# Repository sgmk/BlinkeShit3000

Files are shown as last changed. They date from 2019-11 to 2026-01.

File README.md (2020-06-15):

### BlinkeShit 3000

# New BlinkeShit for Bitwäscherei

An adapted and simplified version of the circuit of the 8Bit Mixtape / Gär-Lämpli to make a little BlinkeShit sign for our new hackerspace collective.

https://github.com/8BitMixtape/8Bit-Mixtape-NEO

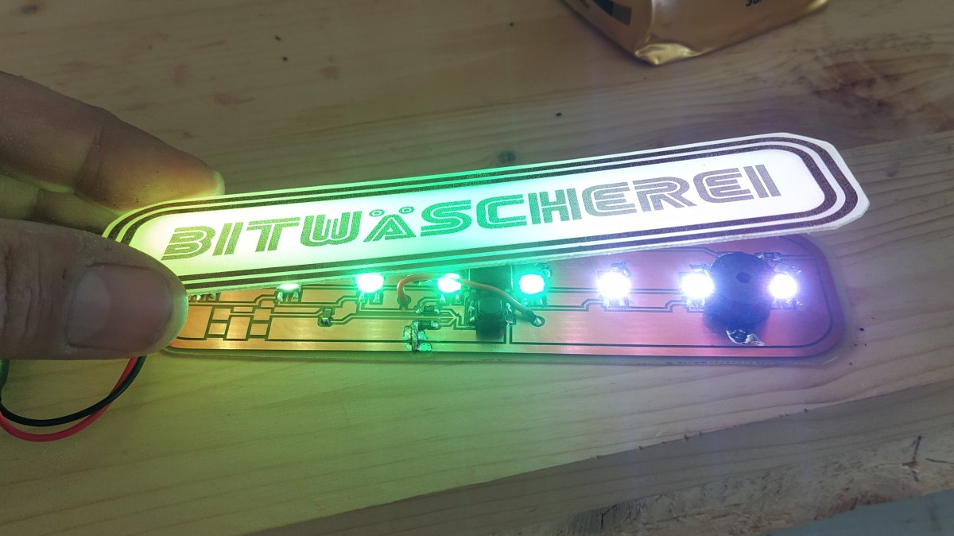
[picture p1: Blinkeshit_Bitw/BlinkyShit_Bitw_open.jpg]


You can design your custom front plate and etch it on PCB or use any other material, paper etc as diffusor.

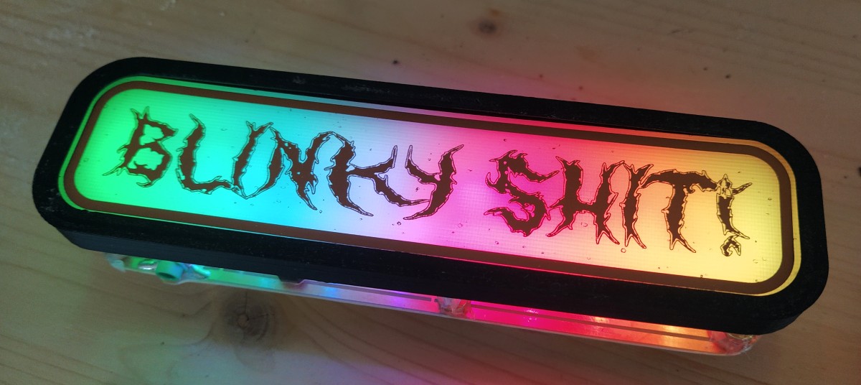
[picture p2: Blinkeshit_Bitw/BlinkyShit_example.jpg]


Upload different BlinkeCode using the Audio Bootloader from arduino IDE:
https://github.com/ChrisMicro/TinyAudioBoot
Best to directly install the full hardware library of the 8bitMixtape to your Arduino IDE, add this to your additional hardware manager: http://8bitmixtape.github.io/package_8bitmixtape_index.json

There are more pins available for adding sensors, pots, buttons etc.

## PCB baseplate

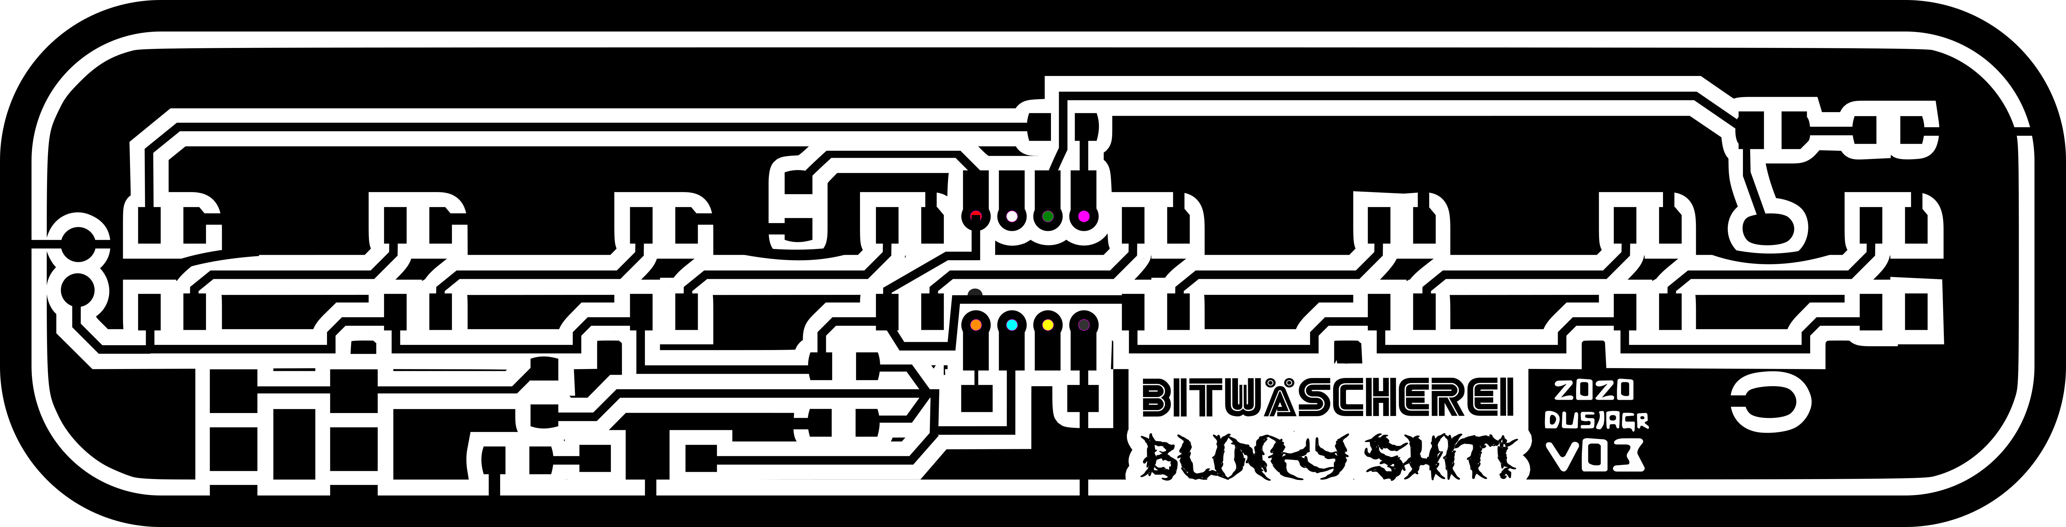
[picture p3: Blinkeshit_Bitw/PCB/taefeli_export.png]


# SGMK X-mas Party "Make DOCK18 Bright Again"
###### Shenzhen is soooo last millenium

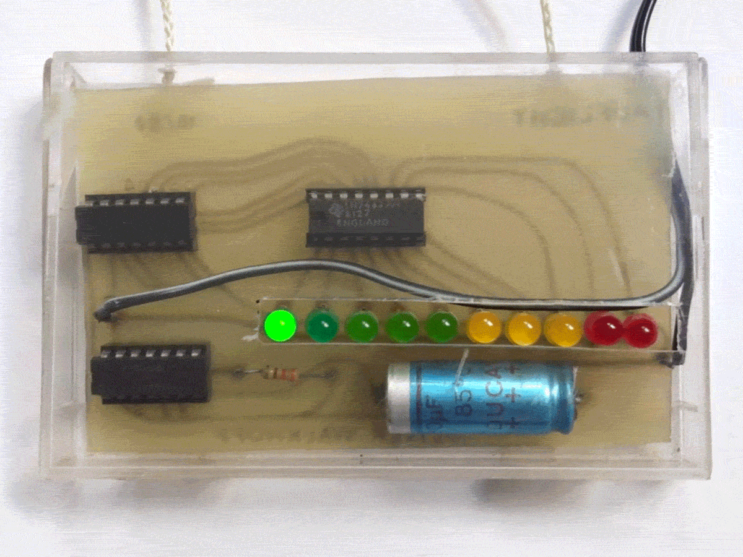
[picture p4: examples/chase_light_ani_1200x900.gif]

(taken from Oli W. website: http://oliverwalkhoff.com/led-chase-light)

# 2019 Entries for BlinkeShit 3000

## International Jury for SGMK BlinkeShit

* David Chen (Taiwan) - openlab Taipei, co-developer of the Taiwanduino
* Scott Beibin (USA) - ...
* Miranda Moss (S.Africa / Sweden) - tries-not-to-be-an-artist, makes solar-powered blinking ginger-roots
* Daniel Eugene Lacey-McDermott (Norway) - Captain Credible
* Yair Reshef (Israel) - Idiot (representing Denisa Kera (global) - PCB connaisseuse and philosopher)
* absent: Budi Prakosa (Indonesia) - Manticore / BadGeek, developer of svg2shenzhen (and much more)

Live Video stream: https://meet.jit.si/BlinkeShit3000-international-jury

## Almost complete selection of entries

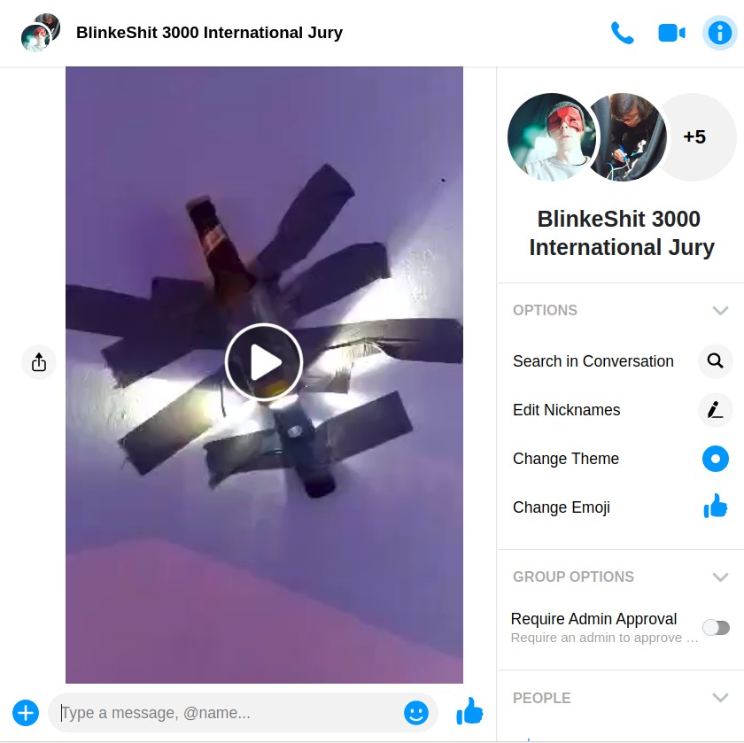
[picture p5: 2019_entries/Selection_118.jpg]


Author: anonymous

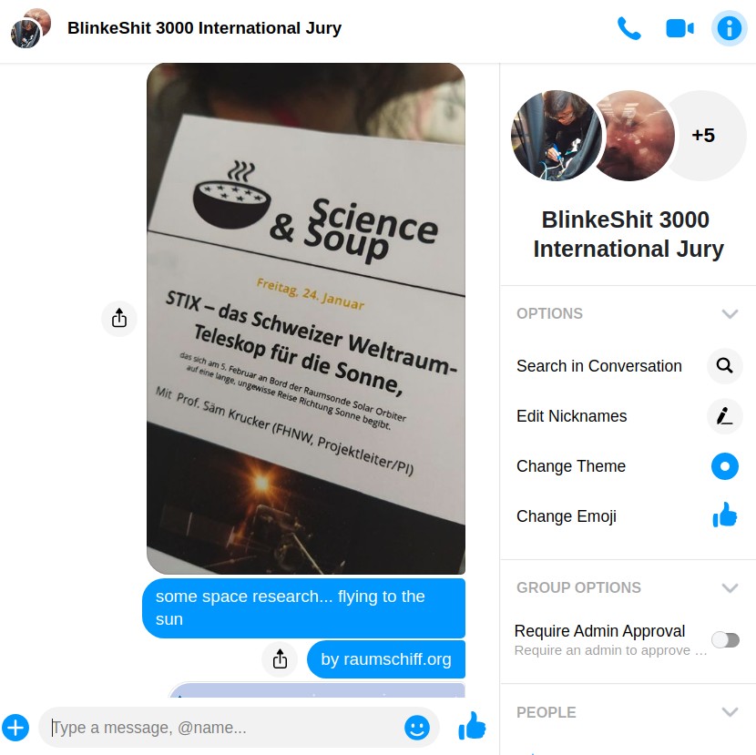
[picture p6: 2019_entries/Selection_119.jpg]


Author: Salome K. in the name of raumschiff

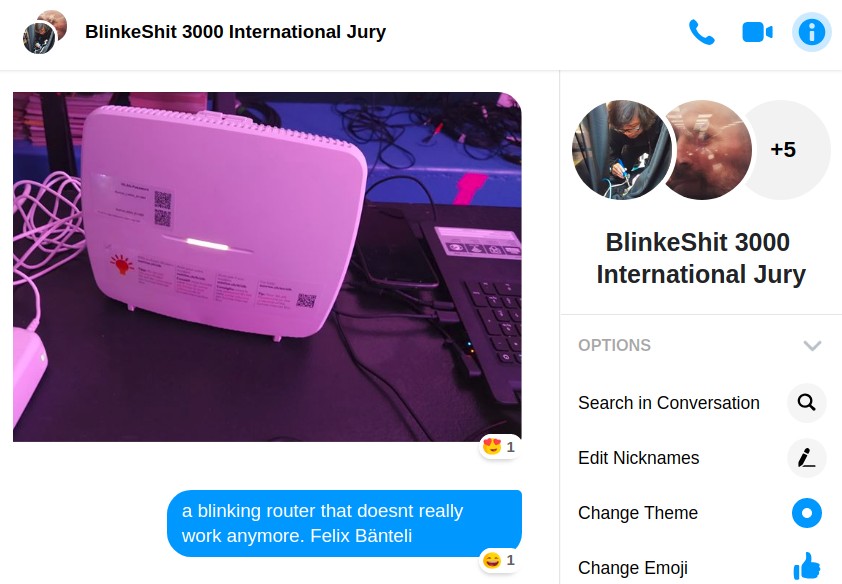
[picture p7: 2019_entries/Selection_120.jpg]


Author: Felix Bänteli and Sunrise not really sponsored 

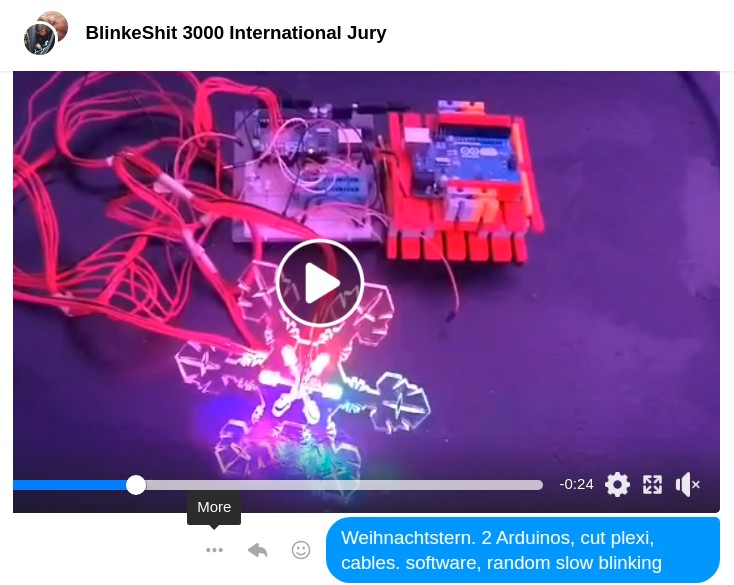
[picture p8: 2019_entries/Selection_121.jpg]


Author: Markus S.

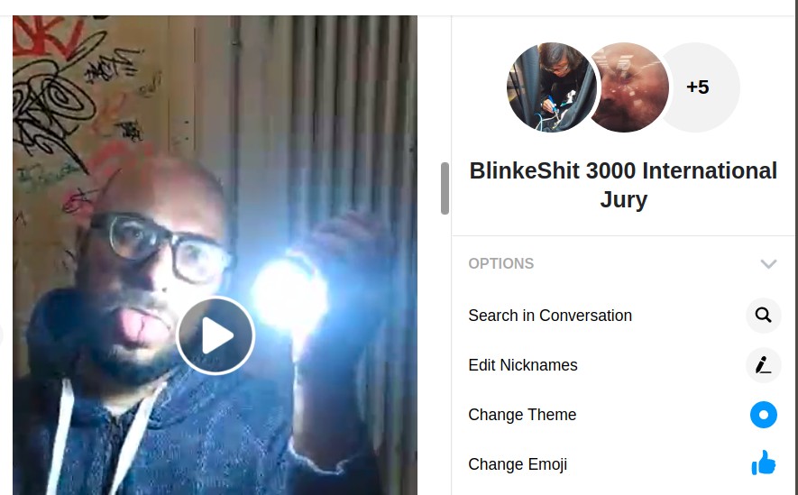
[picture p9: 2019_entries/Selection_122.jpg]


(Free Energy with Mario Purkathofer)

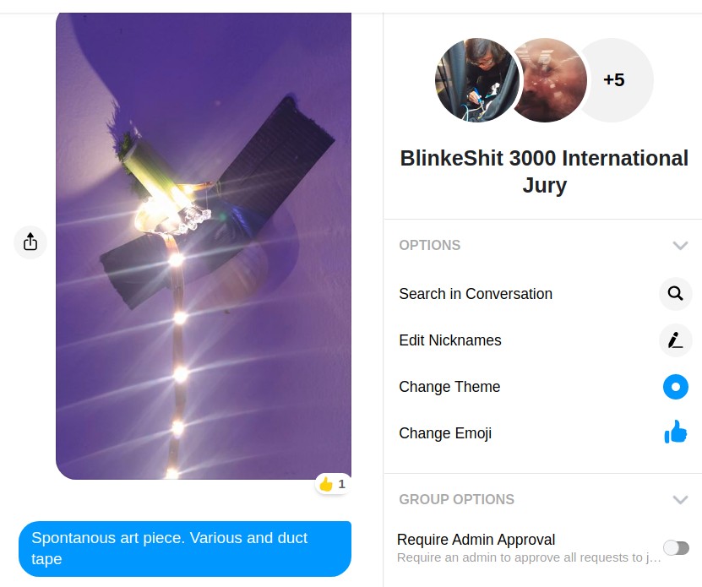
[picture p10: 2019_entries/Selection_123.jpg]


Author: Unknown

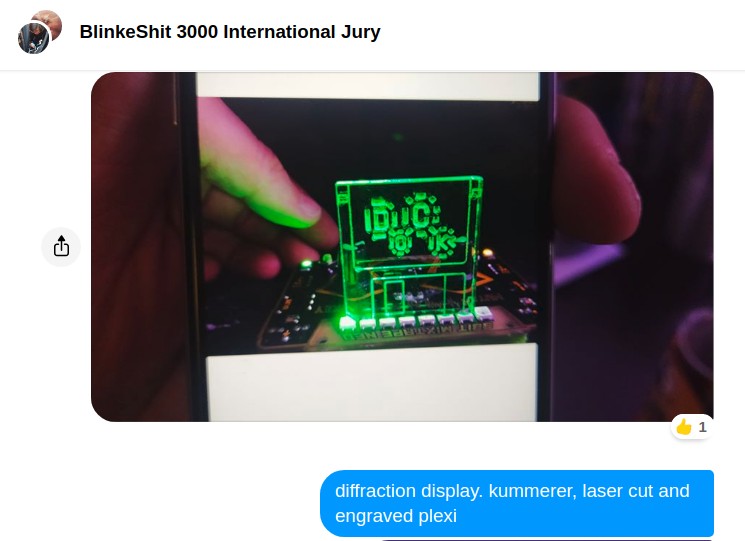
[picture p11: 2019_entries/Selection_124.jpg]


Author: Christoph K.

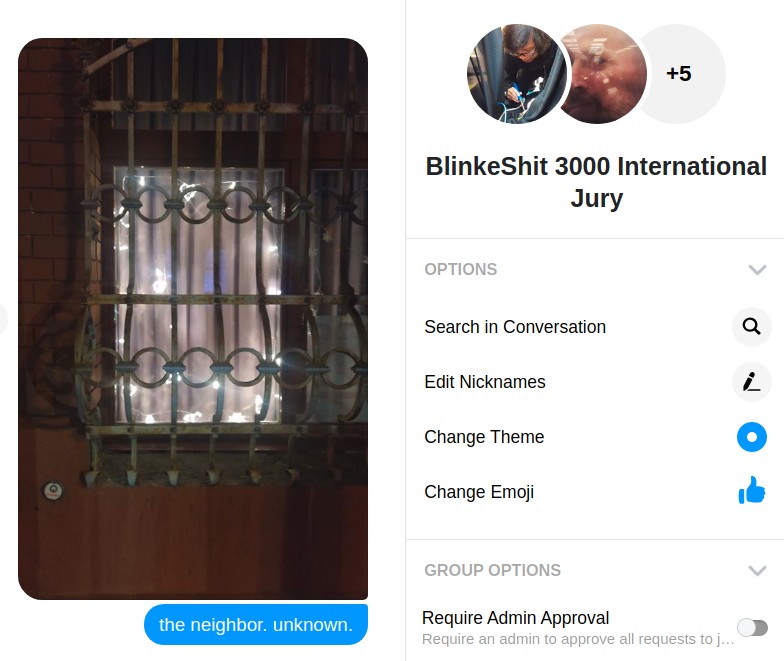
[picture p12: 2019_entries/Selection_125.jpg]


Author: Neighbour (Name unknown)

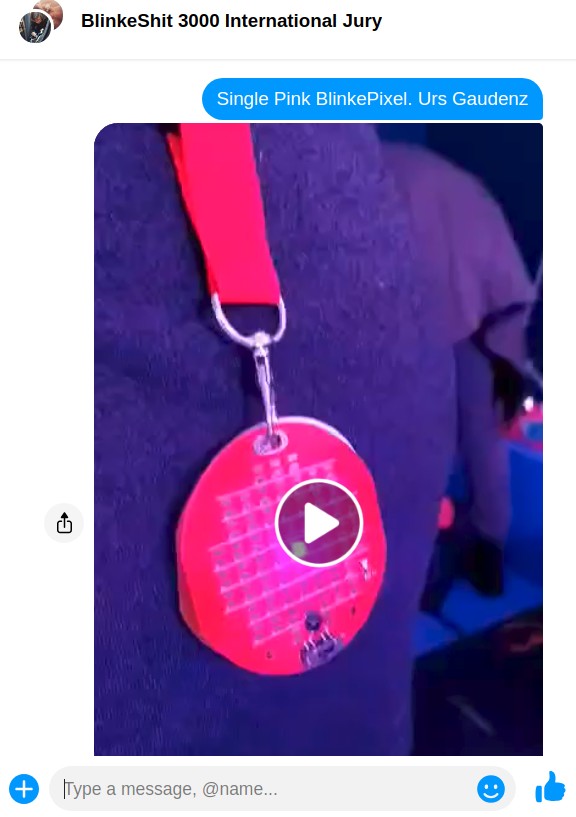
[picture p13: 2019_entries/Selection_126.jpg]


Author: Gaudi. We are still considering to ban Urs Gaudenz from this competition!

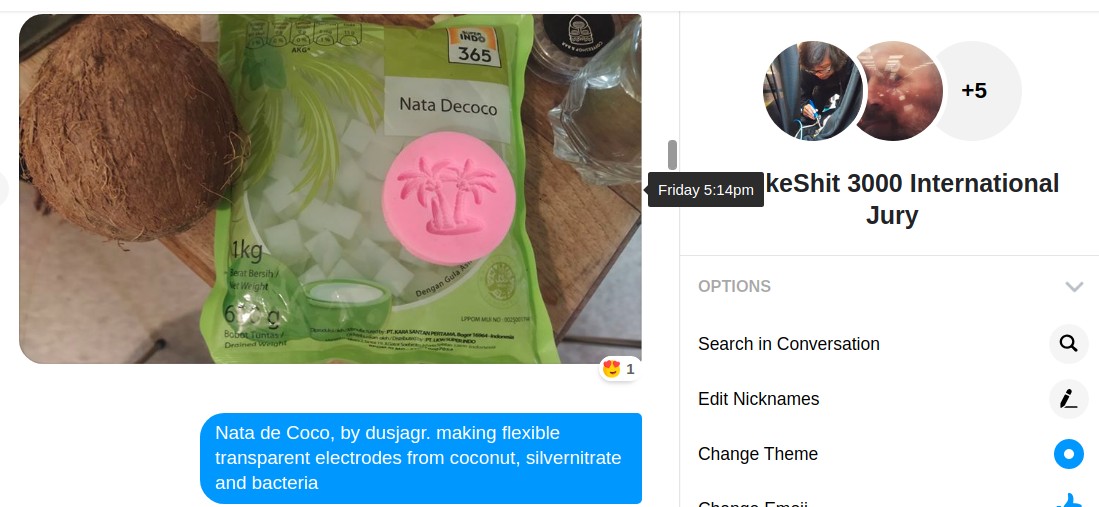
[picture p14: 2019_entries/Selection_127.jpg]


Author: Marc D. aka dusjagr

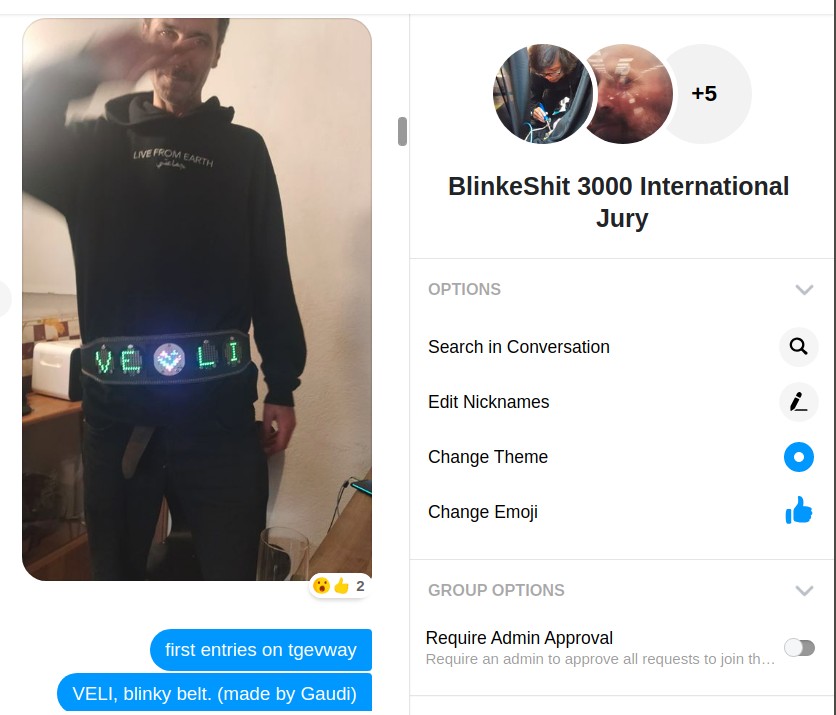
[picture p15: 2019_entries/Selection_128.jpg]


Author: Gaudi present for Veli

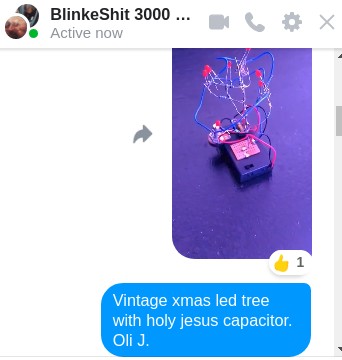
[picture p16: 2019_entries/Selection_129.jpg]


Author: Oliver Jäggi soon to become "a legend"

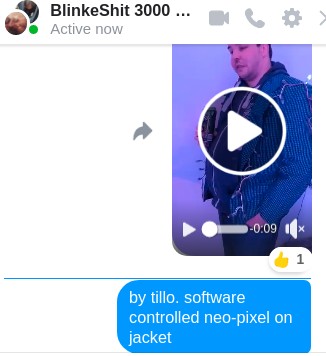
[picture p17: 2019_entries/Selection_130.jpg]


Author: Tillo

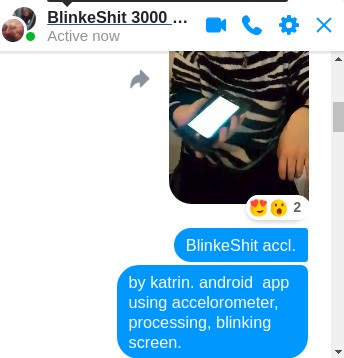
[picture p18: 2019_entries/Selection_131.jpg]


Author: Katrin

# Available components in MechArtLab

## "Official" SGMK BlinkeShit footprint library for KiCAD

See folder... still in progress

## Blinke LEDs RGB

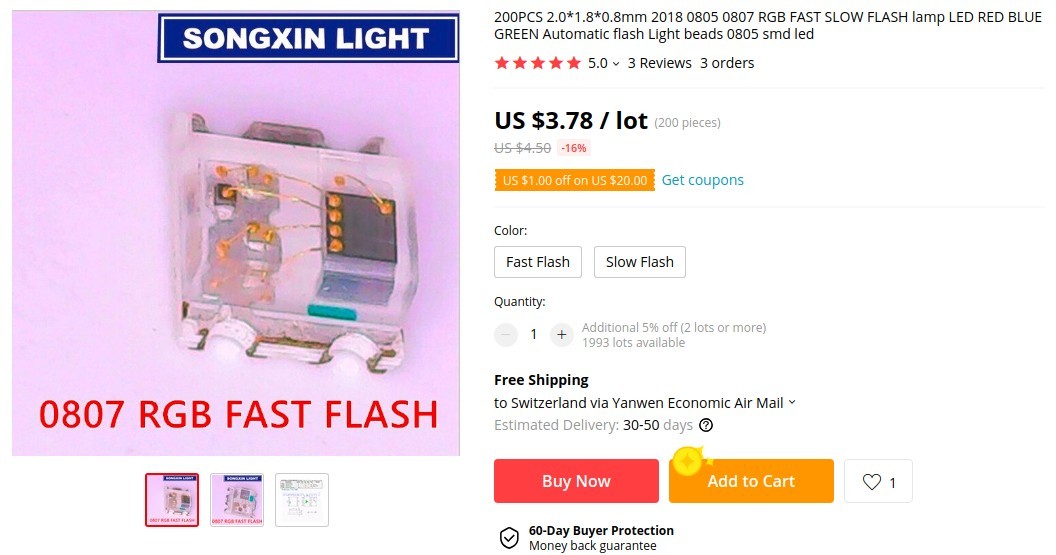
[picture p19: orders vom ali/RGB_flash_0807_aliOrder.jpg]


## Blinke Flash LEDs various colours

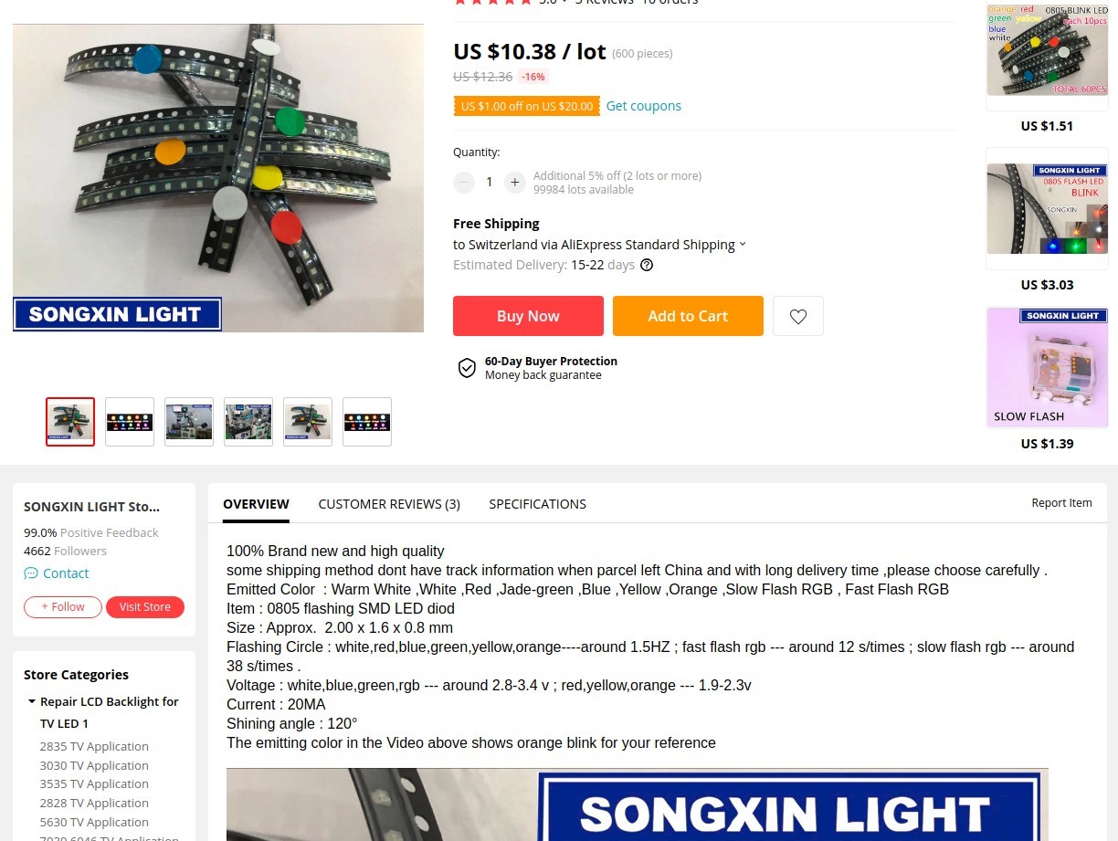
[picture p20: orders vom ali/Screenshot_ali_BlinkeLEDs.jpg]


## NOT-Blinking classic top-LEDs 3528

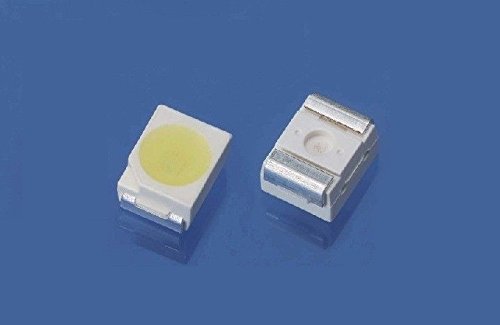
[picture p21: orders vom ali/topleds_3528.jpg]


(for our more-epileptic friends)

## Blinke Pots

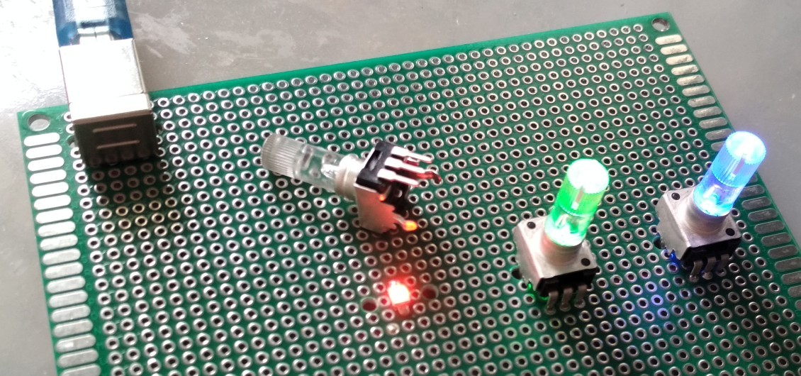
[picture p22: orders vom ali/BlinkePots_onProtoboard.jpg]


Datashit: https://github.com/sgmk/BlinkeShit3000/raw/master/orders%20vom%20ali/RV09BF.pdf

# Classic Examples by the Pioneers of BlinkeShit
## by GaudiLabs

https://github.com/GaudiLabs/BitBadge

## by Gandalf
coming soon...

## by Oli W. "The Legend"
This is one of the first electronic circuits he built, dated October 1982.


(LED chase light, 1982, taken from his website: http://oliverwalkhoff.com/led-chase-light)

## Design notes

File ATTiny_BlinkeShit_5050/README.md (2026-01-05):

# AI-tiny BlinkeShit 3000

Nice little 4x5 pixel display with ATTINY85, Audio bootloader, and (new) 5050 WS2812b RGB LEDs.

## SMD Reflow Workshop

This workshop is primarily to introduce beginners into a very DIY style of reflow soldering using a small number of parts, self-etched PCBs, self-made stencils and simple heaters for reflowing.

## AI slop on 20 pixels

more about this soon!

Visuals can be uploaded from this site: https://dusjagr.github.io/AudioBoot-pio-test/wav/index.html

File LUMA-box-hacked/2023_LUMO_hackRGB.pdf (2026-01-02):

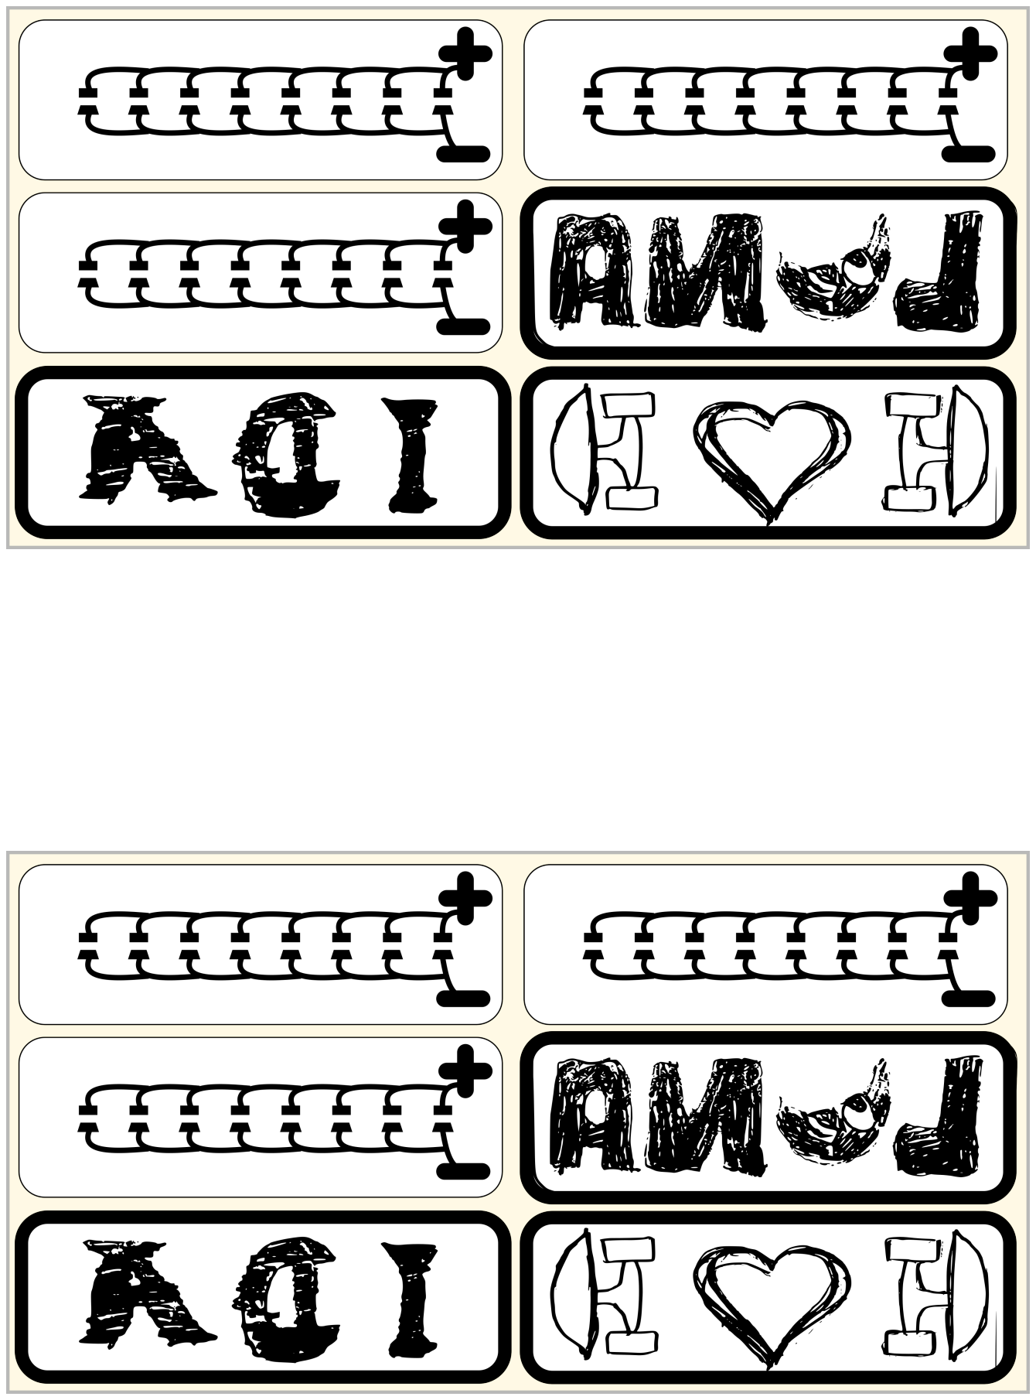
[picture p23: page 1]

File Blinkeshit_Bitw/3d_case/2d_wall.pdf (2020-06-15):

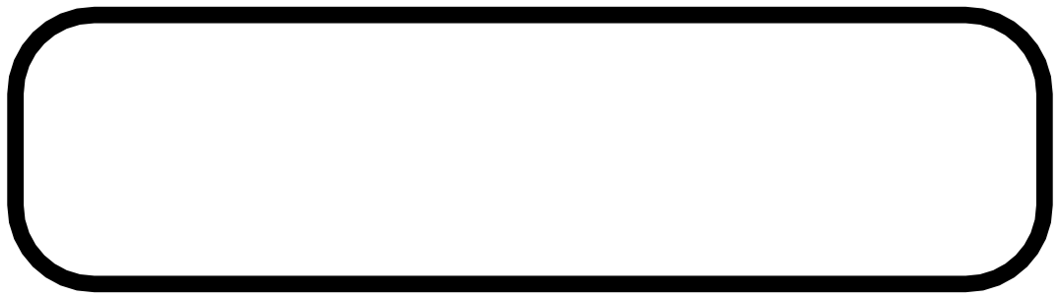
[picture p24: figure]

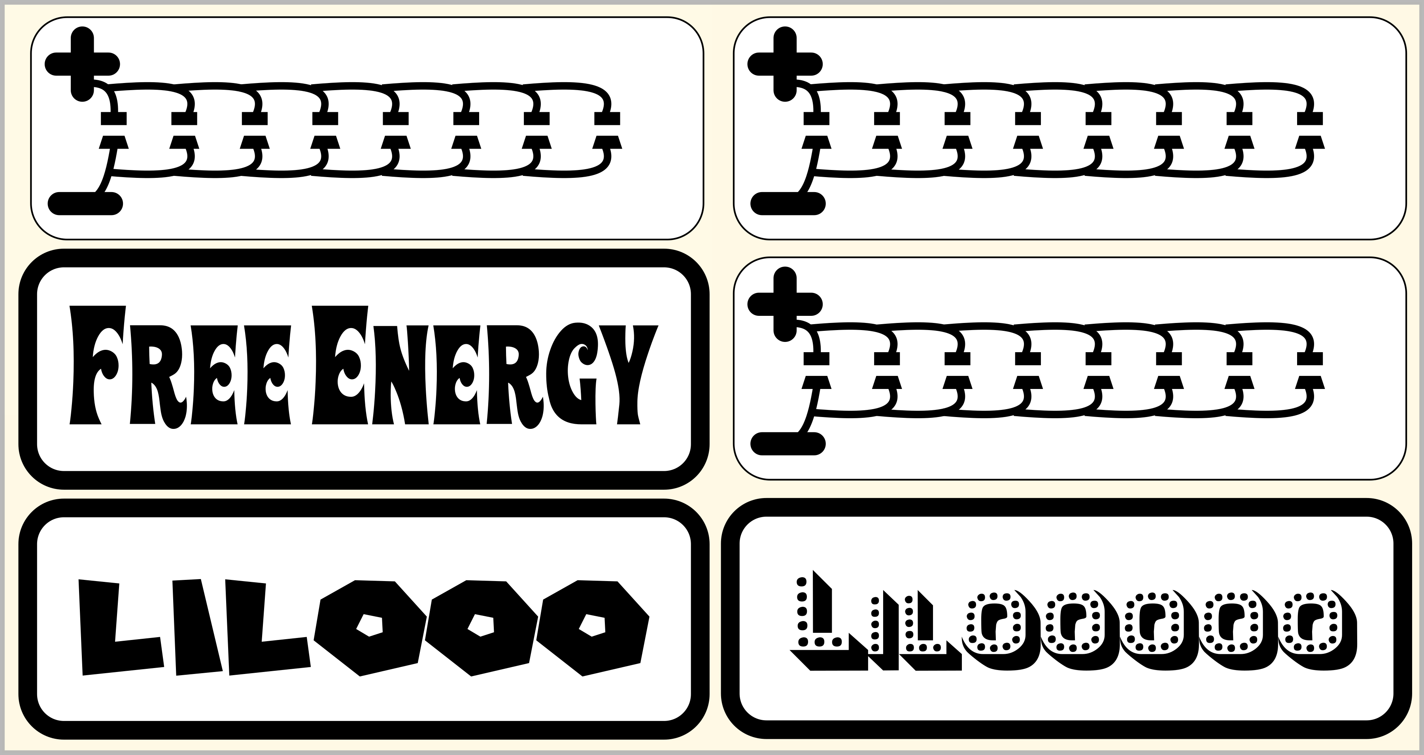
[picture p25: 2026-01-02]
BlinkeTafeli_1.png

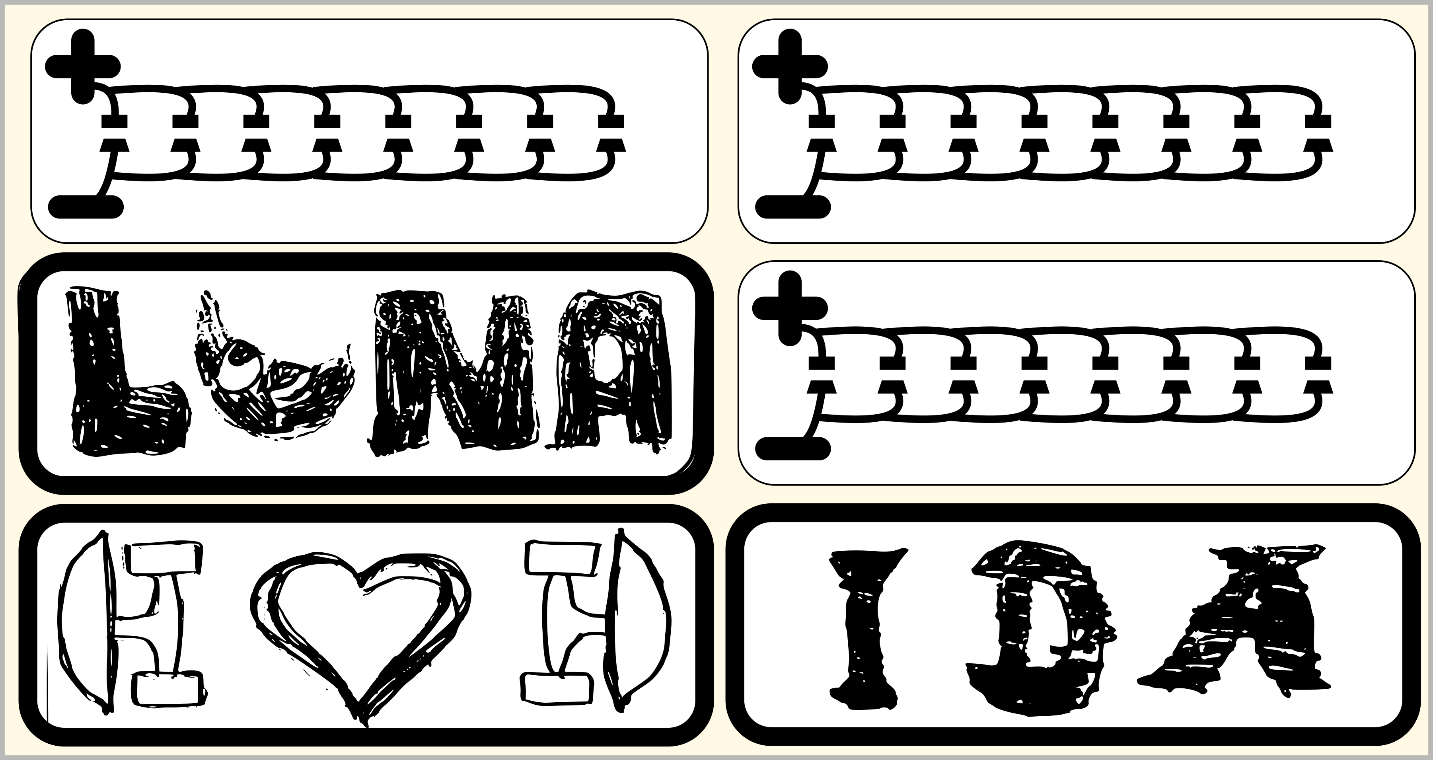
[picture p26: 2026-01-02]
BlinkeTafeli_2.png

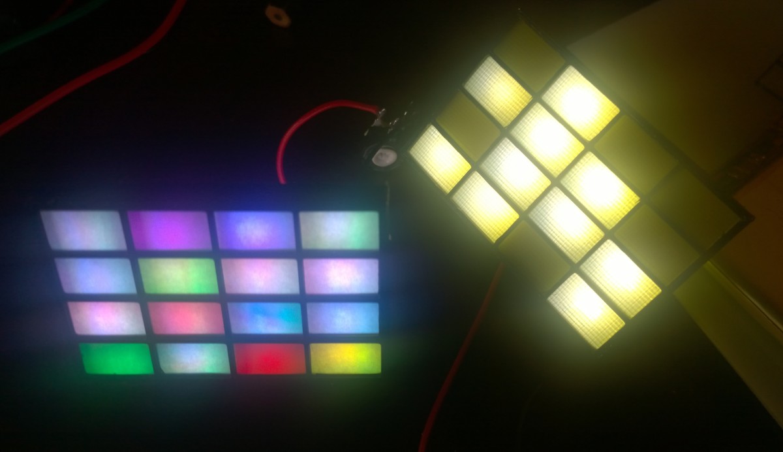
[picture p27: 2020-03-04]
LUMA-box-hacked/Werkspionage_Basel_2020_LUMA-hacked.jpg

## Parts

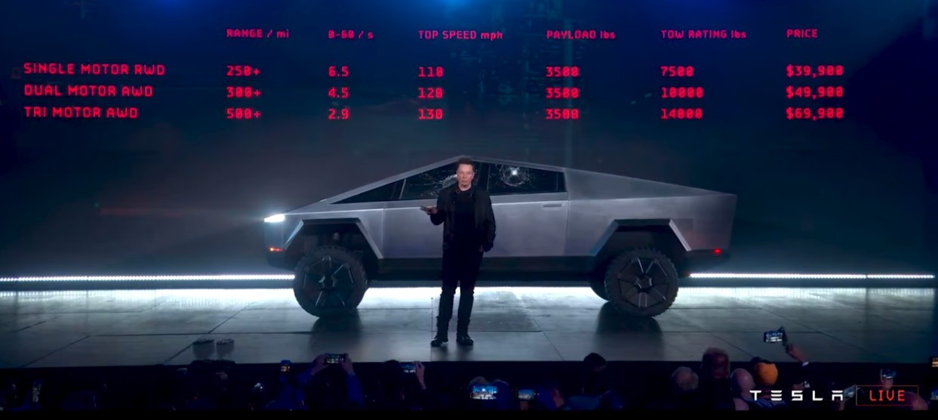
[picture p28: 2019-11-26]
orders vom ali/hure80ies.jpg

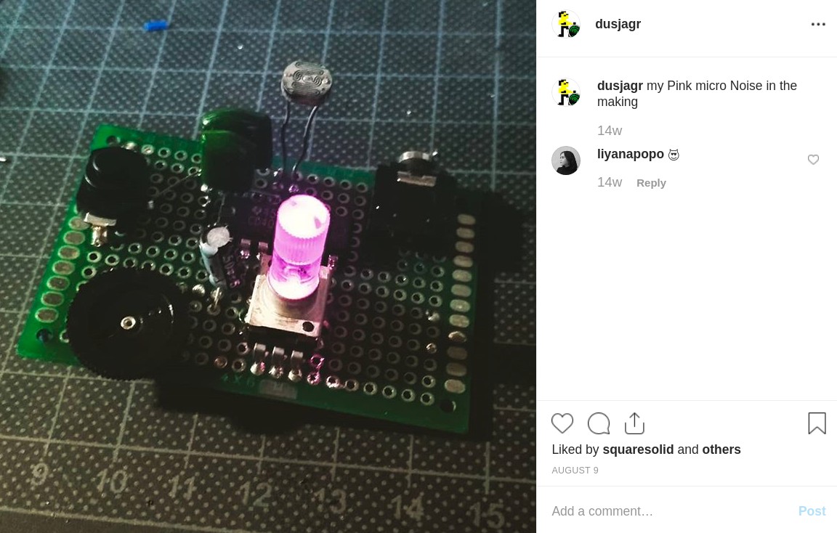
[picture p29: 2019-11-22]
orders vom ali/BlinkePots_prototype.jpg

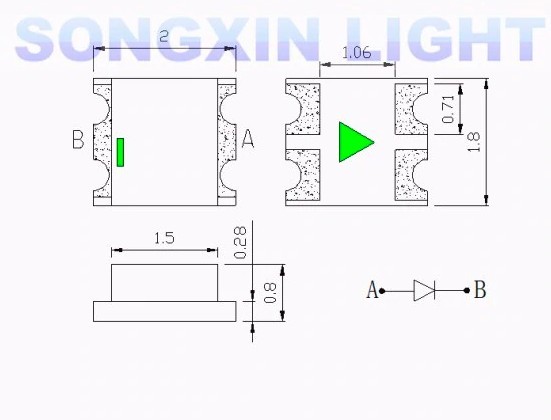
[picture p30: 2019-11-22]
orders vom ali/RGB_flash_0807_footprint.jpg

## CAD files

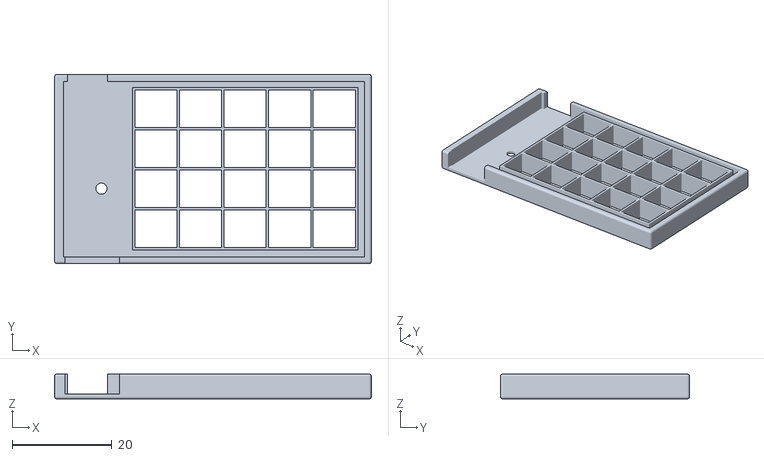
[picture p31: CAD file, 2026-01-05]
ATTiny_BlinkeShit_5050/3d-case/case_open.stl
63.5 x 37.9 x 5.00

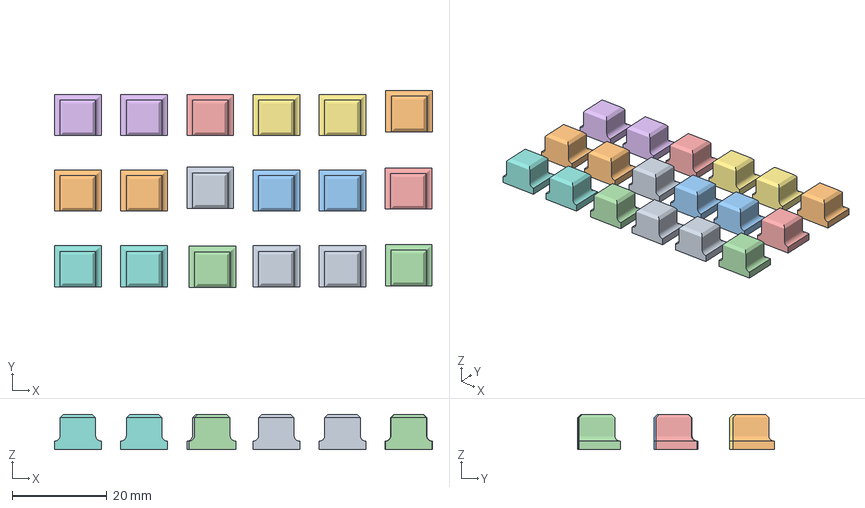
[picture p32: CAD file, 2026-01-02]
Blinkeshit_Bitw/3d_case/CE3_PO-Button.3mf
80.0 x 41.6 x 7.43 mm

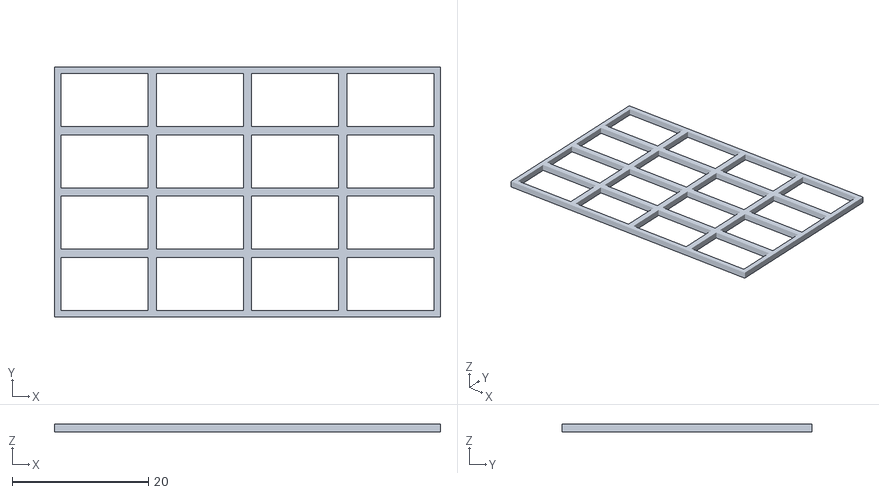
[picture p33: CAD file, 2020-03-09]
LUMA-box-hacked/LUMO_4x4_Top_hackCase.stl
56.7 x 36.7 x 1.20

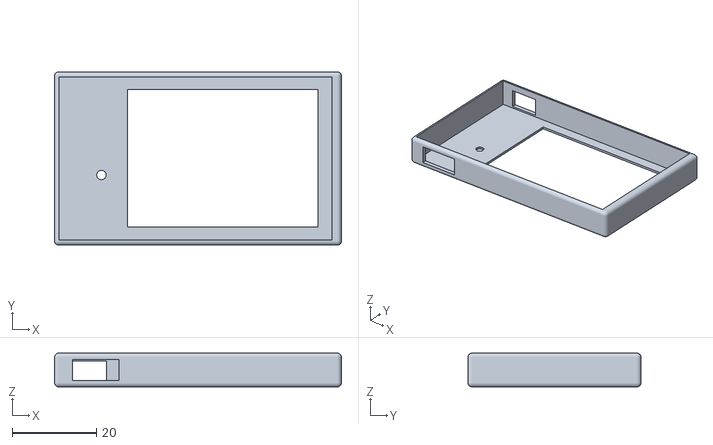
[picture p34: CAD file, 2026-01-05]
ATTiny_BlinkeShit_5050/3d-case/case-Lid.stl
68.1 x 41.1 x 8.00

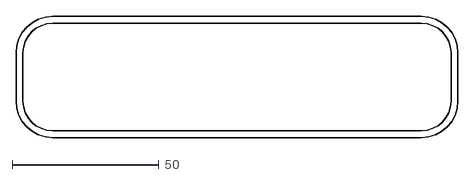
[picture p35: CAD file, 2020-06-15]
Blinkeshit_Bitw/3d_case/2d_wall.dxf
150.6 x 41.4

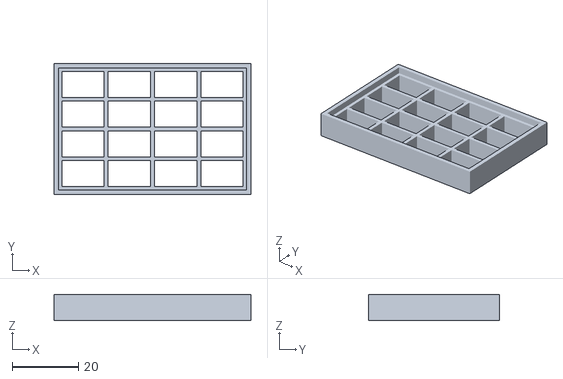
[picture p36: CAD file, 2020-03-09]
LUMA-box-hacked/LUMO_4x4_hackCase.stl
59.6 x 39.6 x 8.00

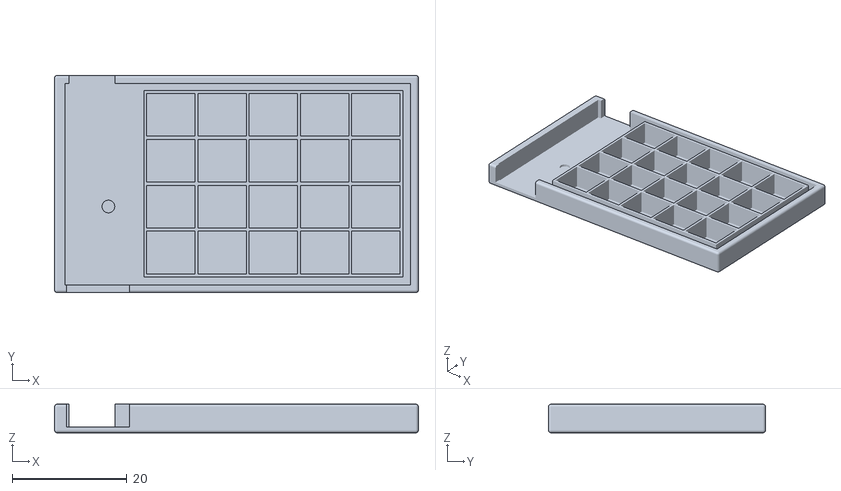
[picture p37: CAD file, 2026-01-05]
ATTiny_BlinkeShit_5050/3d-case/case_close_012mm.stl
63.5 x 37.9 x 5.00

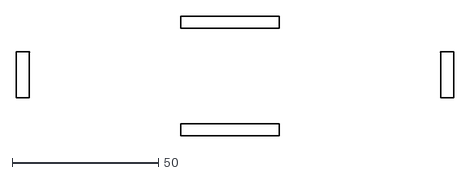
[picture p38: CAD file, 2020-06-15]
Blinkeshit_Bitw/3d_case/2d_randli.dxf
149.6 x 40.8

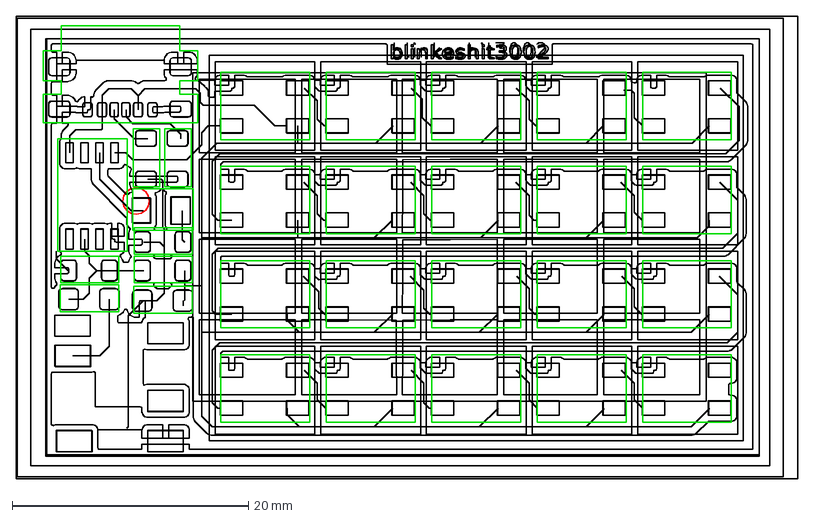
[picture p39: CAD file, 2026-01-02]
ATTiny_BlinkeShit_5050/3d-case/case_grid.dxf
66.1 x 39.1 mm

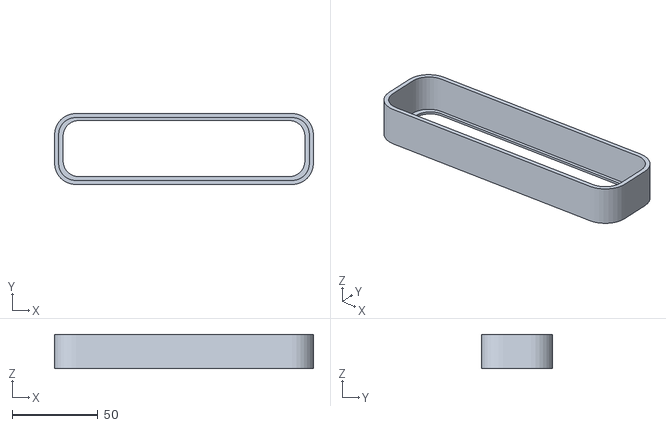
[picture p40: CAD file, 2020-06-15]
Blinkeshit_Bitw/3d_case/BlinkeShit_Case_kafi.stl
150.6 x 41.4 x 20.0

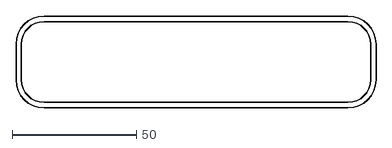
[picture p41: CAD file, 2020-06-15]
Blinkeshit_Bitw/3d_case/2s_Border_inner.dxf
145.0 x 37.0

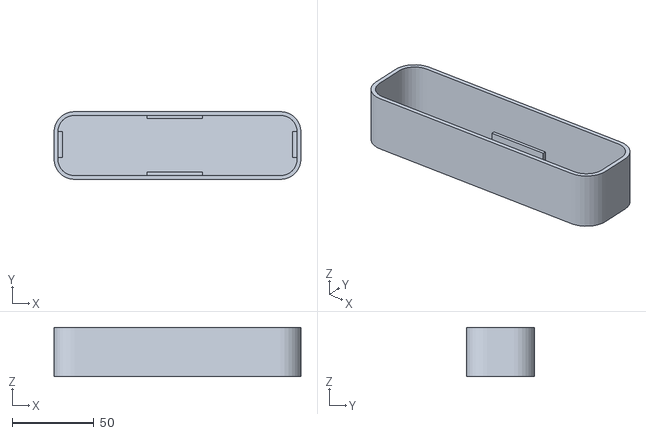
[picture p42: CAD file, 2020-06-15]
Blinkeshit_Bitw/3d_case/BlinkeShit_Case.stl
150.6 x 41.4 x 30.0

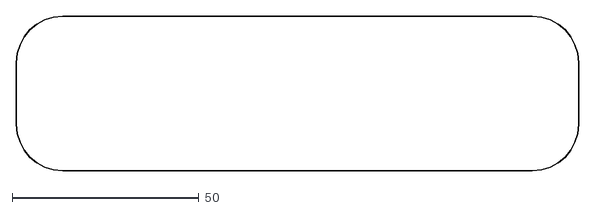
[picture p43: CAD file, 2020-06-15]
Blinkeshit_Bitw/3d_case/2d_cover.dxf
150.6 x 41.4

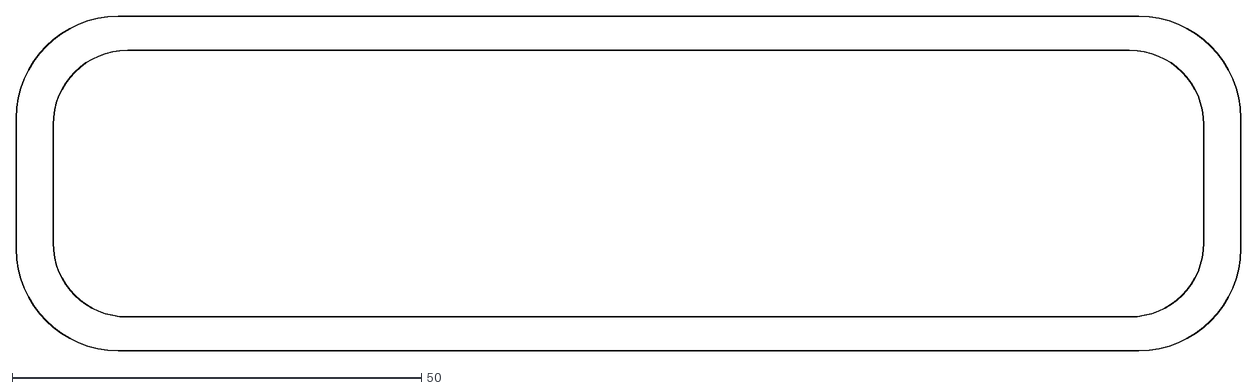
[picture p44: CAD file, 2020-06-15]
Blinkeshit_Bitw/3d_case/2d_top.dxf
149.6 x 40.8

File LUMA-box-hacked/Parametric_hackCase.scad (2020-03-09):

// BlinkeShit Frame-Generator Version 3000


WallThickness = 1.2;
OuterWall = 1.8;
StepThickness = WallThickness + 0.8;
Height = 8;
StepHeight = 1.6;

CoverHeight = 1.2;

//LengthX = 80;
//WidthY = 60; 

SizeX = 14;
SizeY = 9;

GridNrX  = 4;
GridNrY = 4;


LengthX = GridNrX*SizeX+OuterWall*2;
WidthY = GridNrY*SizeY+OuterWall*2;

translate([0,0,Height/2])
difference() {
  translate([LengthX/2-OuterWall,WidthY/2-OuterWall,0]) cube(size = [LengthX,WidthY,Height], center = true);
   
  for ( j = [1 : 1 : GridNrY] ){  
    for ( i = [1 : 1 : GridNrX] ){
    translate([i*SizeX-SizeX/2,j*SizeY-SizeY/2,0]) cube(size = [SizeX-WallThickness,SizeY-WallThickness,Height+1], center = true);
    
    }
  }  
  
  
  
  for ( j = [1 : 1 : GridNrY] ){  
    for ( i = [1 : 1 : GridNrX] ){
    translate([i*SizeX-SizeX/2,j*SizeY-SizeY/2,Height-StepHeight]) cube(size = [SizeX-WallThickness+StepThickness,SizeY-WallThickness+StepThickness,Height+1], center = true);
    
    }
  }  
}



//translate([0,0,CoverHeight/2+Height-CoverHeight])
translate([80,0,CoverHeight/2])
difference() {
  translate([35,22.5,0]) cube(size = [LengthX-OuterWall*2,WidthY-OuterWall*2,CoverHeight], center = true);
    
  for ( j = [1 : 1 : 4] ){  
    for ( i = [1 : 1 : 4] ){
    translate([i*14,j*9,0]) cube(size = [14-WallThickness,9-WallThickness,CoverHeight+1], center = true);
    
    }
  }  
  
}

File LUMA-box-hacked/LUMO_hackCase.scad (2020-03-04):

//14 9
WallThickness = 0.8;
StepThickness = 1.8;
Height = 8;
StepHeight = 1.6;

CoverHeight = 1.2;

translate([0,0,Height/2])
difference() {
  translate([35,22.5,0]) cube(size = [58,38,Height], center = true);
    
  for ( j = [1 : 1 : 4] ){  
    for ( i = [1 : 1 : 4] ){
    translate([i*14,j*9,0]) cube(size = [14-WallThickness,9-WallThickness,Height+1], center = true);
    
    }
  }  
  for ( j = [1 : 1 : 4] ){  
    for ( i = [1 : 1 : 4] ){
    translate([i*14,j*9,Height-StepHeight]) cube(size = [14-WallThickness+StepThickness,9-WallThickness+StepThickness,Height+1], center = true);
    
    }
  }  
}

//translate([80,0,CoverHeight/2+Height-CoverHeight])
translate([80,0,0])
difference() {
  translate([35,22.5,0]) cube(size = [58-1.2,38-1.2,CoverHeight], center = true);
    
  for ( j = [1 : 1 : 4] ){  
    for ( i = [1 : 1 : 4] ){
    translate([i*14,j*9,0]) cube(size = [14-WallThickness,9-WallThickness,CoverHeight+1], center = true);
    
    }
  }  
  
}

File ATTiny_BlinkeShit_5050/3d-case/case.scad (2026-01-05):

$fn = 96;

cover = 0.00; // imcrease to approx 0.1 to 0.2 for a thin diffusion layer

case();
lid();

module case() {
rotate([180,0,0]) union(){
linear_extrude(height = 5, center = true, convexity = 10)
		import(file = "case_grid.dxf", layer = "grid");

difference(){
    minkowski(){
    translate([0,0,-0]) linear_extrude(height = 4, center = true, convexity = 10)
		import(file = "case_grid.dxf", layer = "border");
        sphere(d=1);
    }
    translate([0,0,-0.6])linear_extrude(height = 5, center = true, convexity = 10)
		import(file = "case_grid.dxf", layer = "inner");
    translate([7,40,-1]) cube([11, 10, 5], center=true);
    translate([6,0,-0.6]) cube([8, 10, 5], center=true);
    translate([0,0,-0.5-cover])linear_extrude(height = 6, center = true, convexity = 10)
		import(file = "case_grid.dxf", layer = "cut");
    translate([0,0,-0.5-cover]) linear_extrude(height = 6, center = true, convexity = 10)
		import(file = "case_grid.dxf", layer = "LED");
  }
}
}

// thin coverlayer
/*
difference(){
translate([0,0,2.5]) linear_extrude(height = 0.12, center = true, convexity = 10)
		import(file = "case_grid.dxf", layer = "border");
    #translate([9,26.5,-0.6]) cylinder(20, d=2, center=true, $fn=30);
}
*/

// lid

module lid() {
rotate([180,0,0]) translate([75,0,2.5]) difference(){
    minkowski(){
translate([0,0,-1]) linear_extrude(height = 6, center = true, convexity = 10)
		import(file = "case_grid.dxf", layer = "Topborder");
        sphere(d=2);
    }
    translate([0,0,-1.6]) linear_extrude(height = 8, center = true, convexity = 10)
		import(file = "case_grid.dxf", layer = "Tobinner");
    translate([0,0,-0.0-cover]) linear_extrude(height = 6, center = true, convexity = 10)
		import(file = "case_grid.dxf", layer = "LED");
    translate([0,0,0])linear_extrude(height = 7, center = true, convexity = 10)
		import(file = "case_grid.dxf", layer = "cut");
    translate([7.5,40,-1]) cube([11, 10, 5], center=true);
    translate([6,0,-0.6]) cube([8, 10, 5], center=true);
    
}
}

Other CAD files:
Blinkeshit_Bitw/3d_case/BlinkeShit_Case.scad

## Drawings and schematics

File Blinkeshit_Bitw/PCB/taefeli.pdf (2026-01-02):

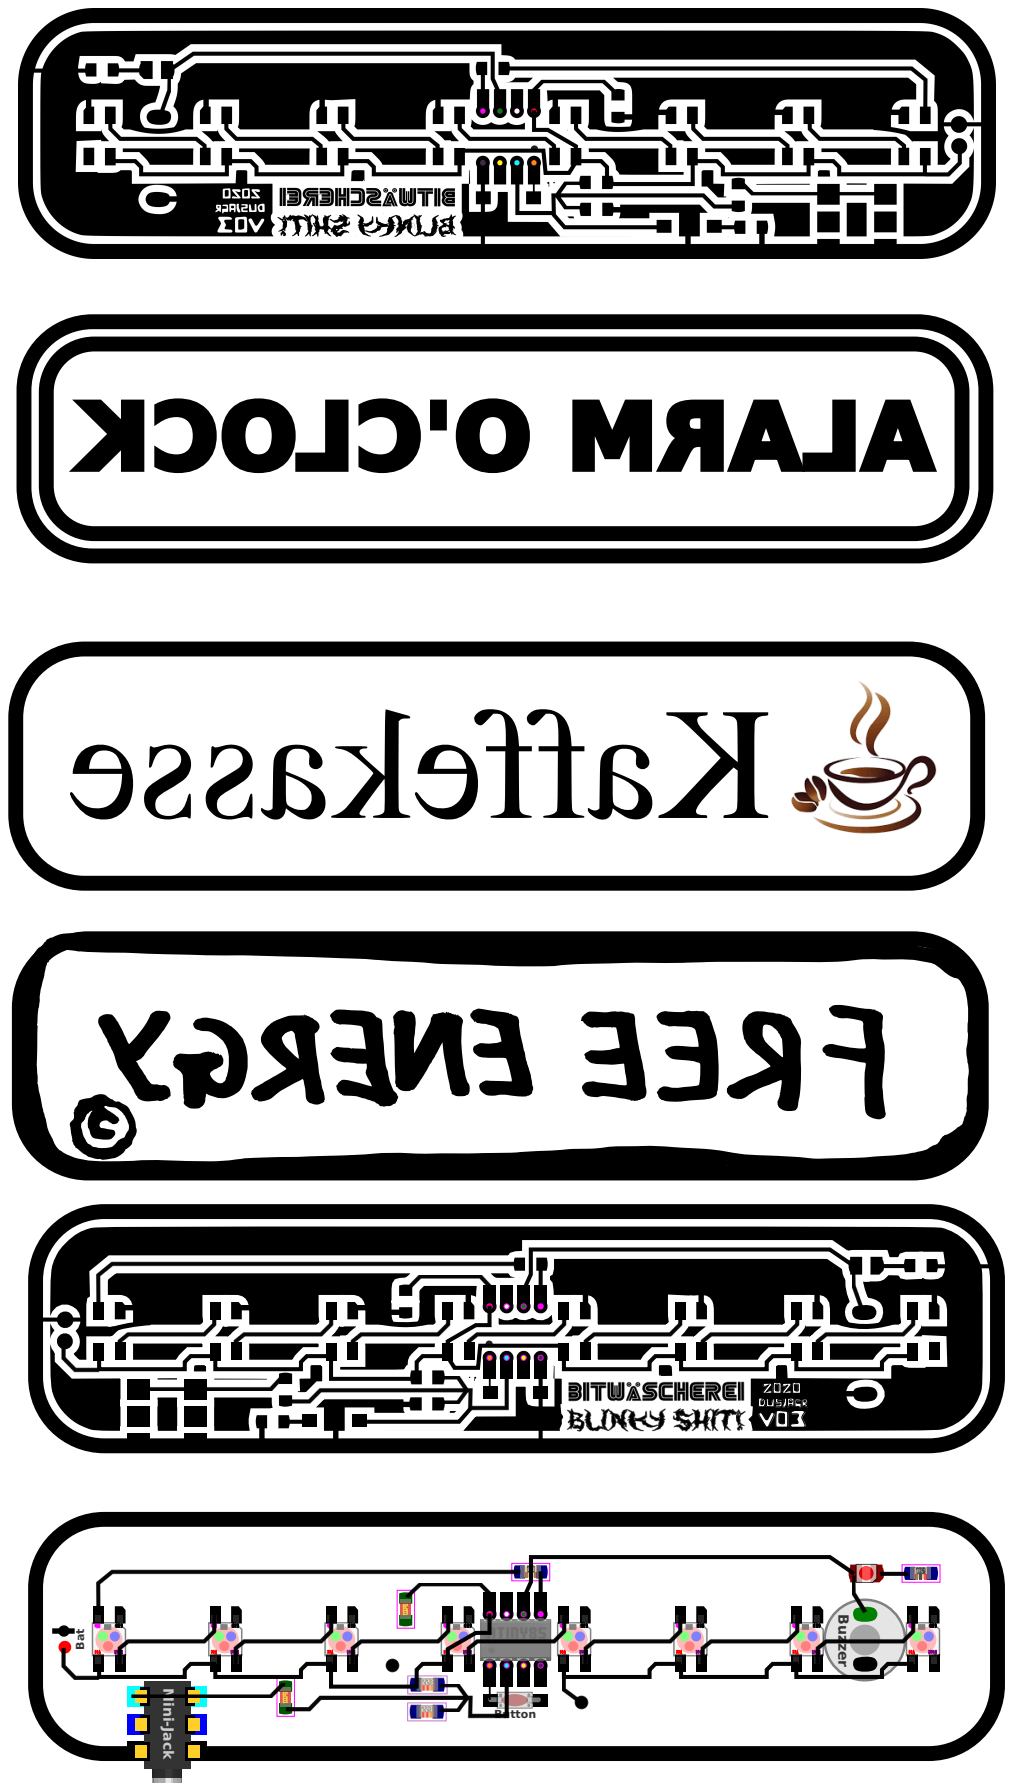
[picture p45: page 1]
Din GND; Dout Vcc; ni D DNG; ccV t uoD; Mini-Jack; 1O2 Buzzer; Bat; Button; v03 dusjagr

KC OLC' O MRAL A

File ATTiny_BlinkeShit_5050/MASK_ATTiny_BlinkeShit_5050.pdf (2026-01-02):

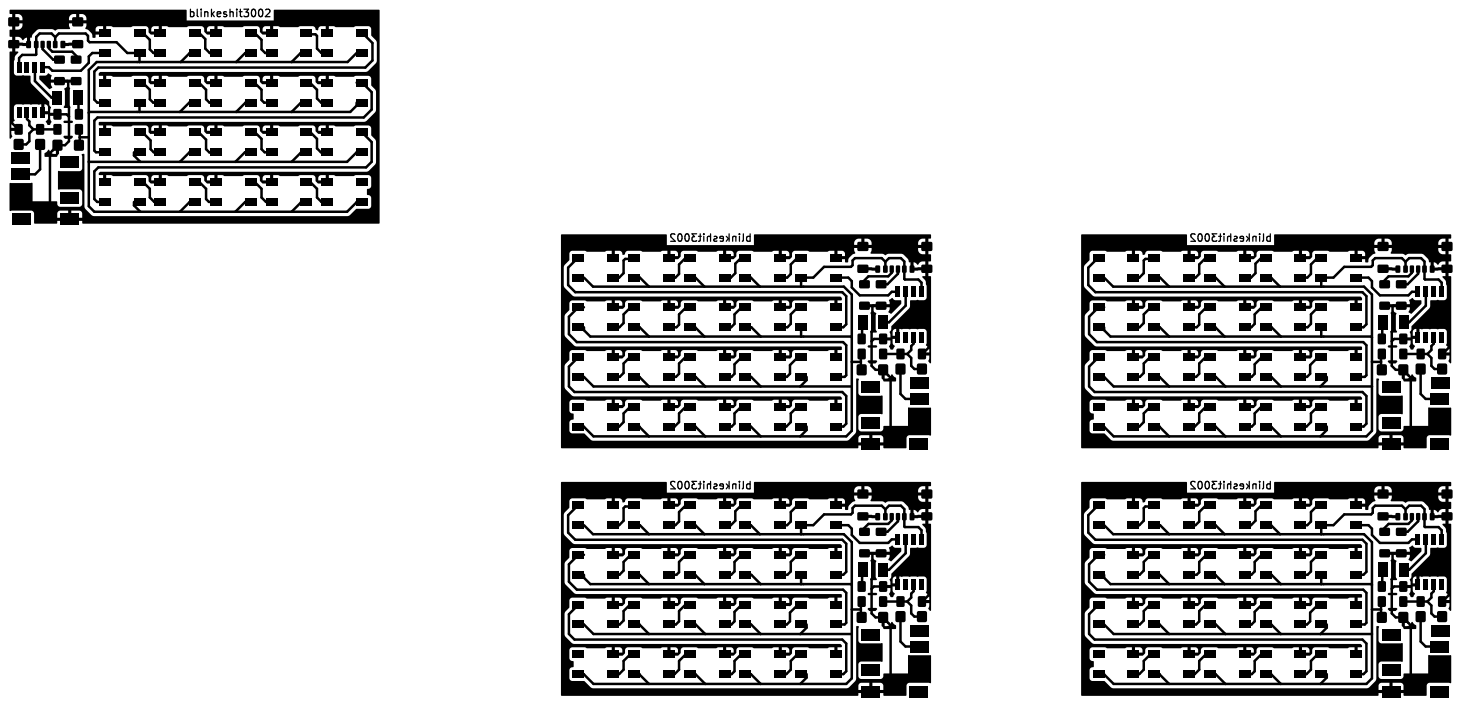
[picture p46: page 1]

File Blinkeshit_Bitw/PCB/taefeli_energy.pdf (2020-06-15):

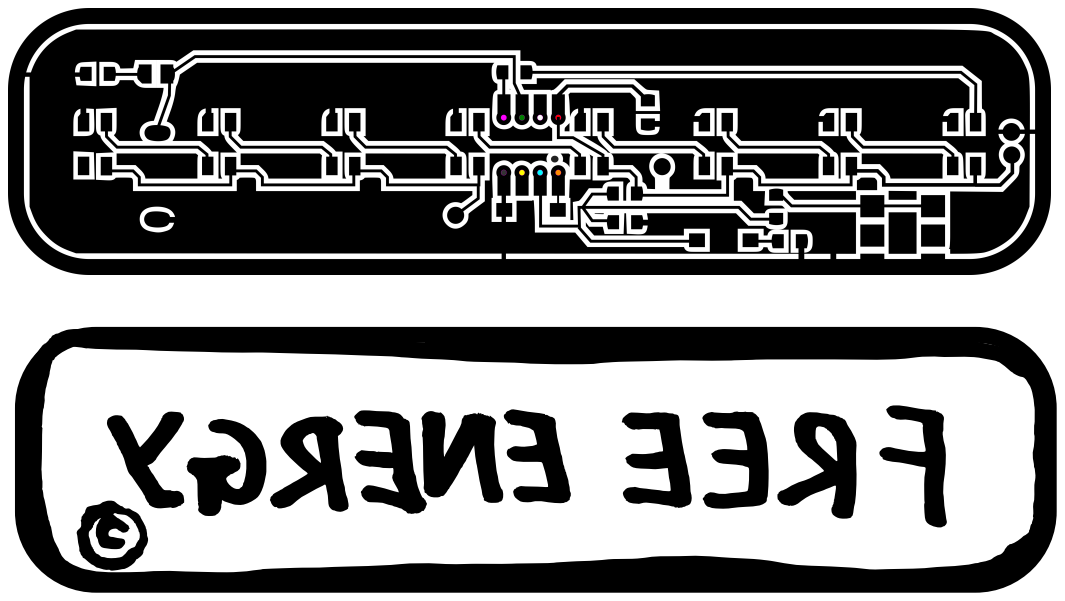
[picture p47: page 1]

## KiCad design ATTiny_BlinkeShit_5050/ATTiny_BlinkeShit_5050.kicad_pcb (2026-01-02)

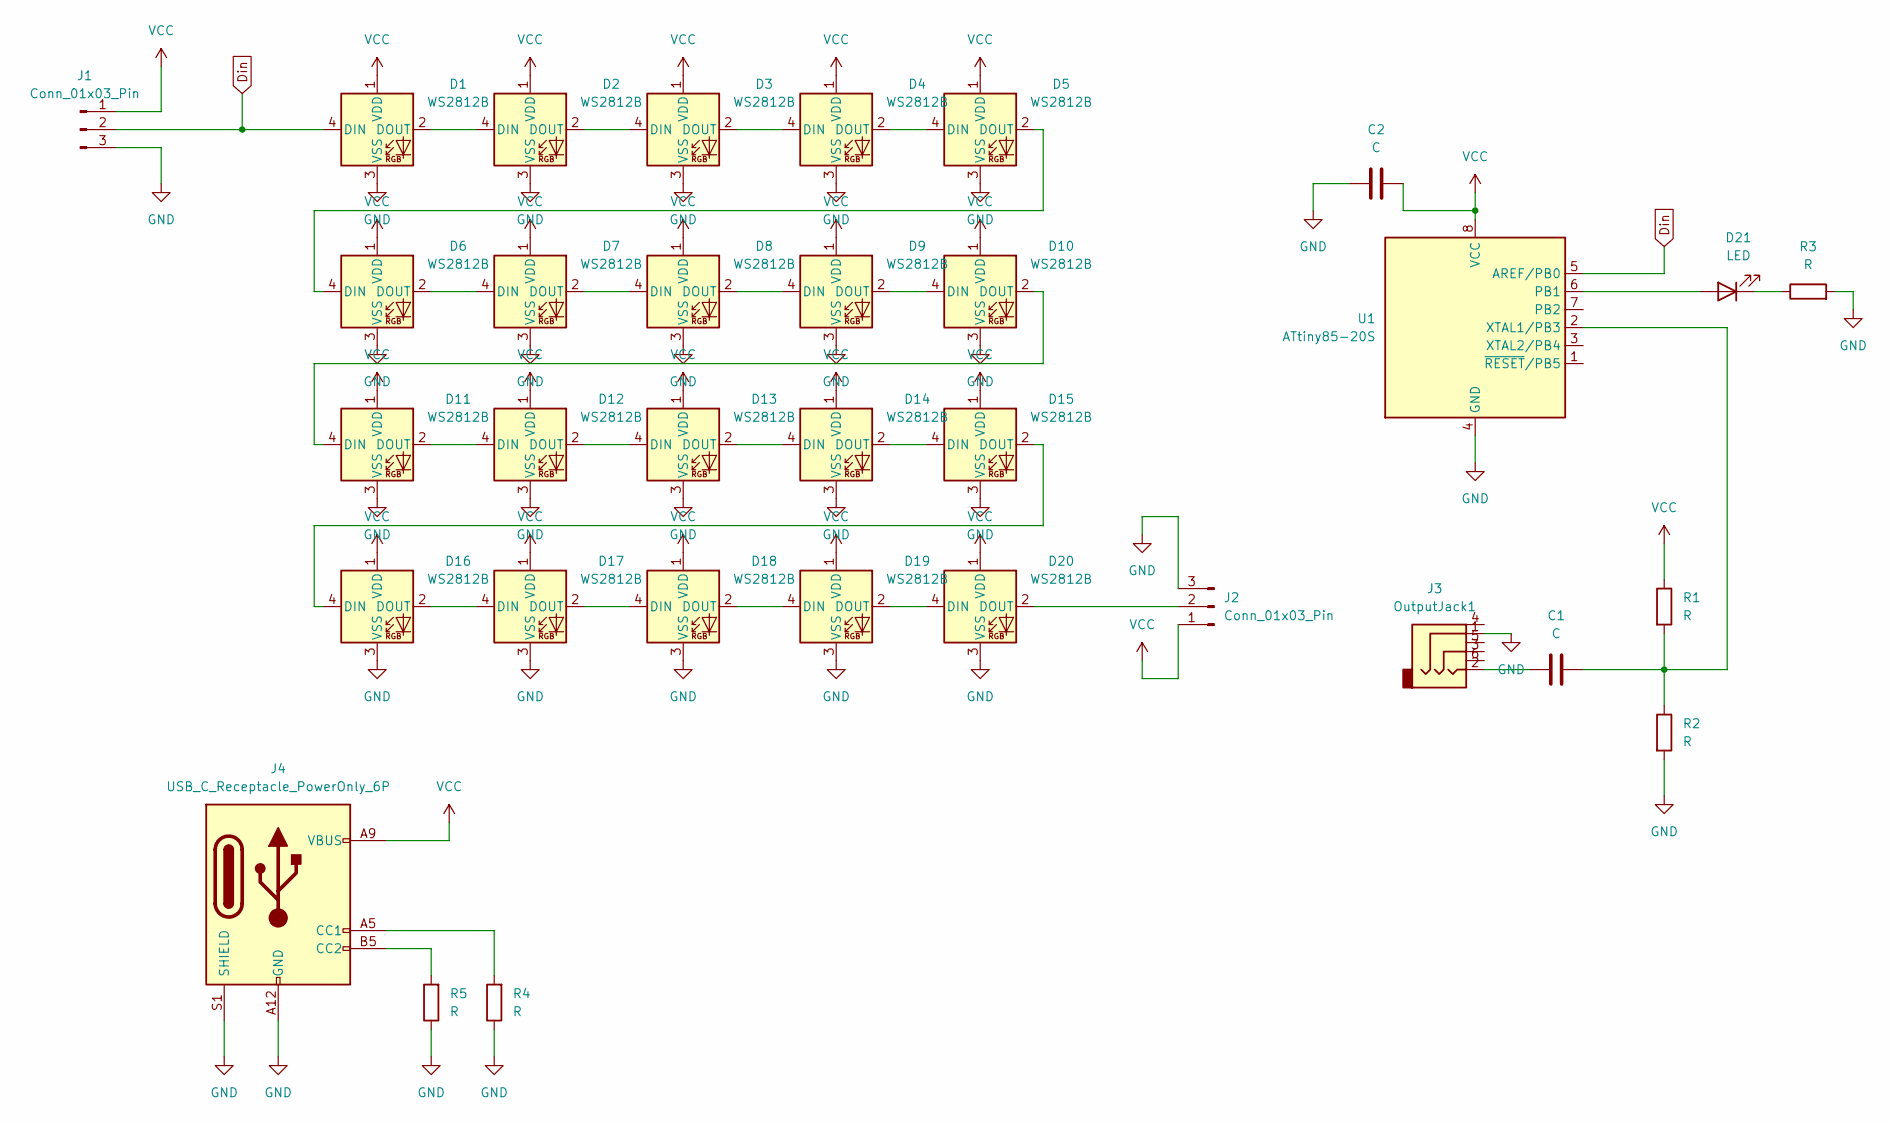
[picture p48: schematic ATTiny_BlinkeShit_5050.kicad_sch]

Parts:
C1, C2: C; C_1210_noGND
D1, D2, D3, D4, D5, D6, D7, D8, D9, D10, D11, D12, D13, D14, D15, D16, D17, D18, D19, D20: WS2812B; Mixtape_NEO_WS2812B_3d
D21: LED; LED_PLCC_2835_Handsoldering
J1, J2: Conn_01x03_Pin; PinSocket_1x03_P2.54mm_Vertical
J3: OutputJack1; 3.5mm_jack_SMT_dusjagrNew
J4: USB_C_Receptacle_PowerOnly_6P; USB_C_Receptacle_GCT_USB4135-GF-A_6P_TopMnt_Horizontal
R1, R2: R; R_1206_noGND
R3, R4, R5: R; R_1206_noGND_noSilk
U1: ATtiny85-20S; SOIC-8W_5.3x5.3mm_P1.27mm

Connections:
Din: D1.4 (DIN), J1.2, U1.5 (AREF/PB0)
GND: C2.1, D1.3 (VSS), D2.3 (VSS), D3.3 (VSS), D4.3 (VSS), D5.3 (VSS), D6.3 (VSS), D7.3 (VSS), D8.3 (VSS), D9.3 (VSS), D10.3 (VSS), D11.3 (VSS), D12.3 (VSS), D13.3 (VSS), D14.3 (VSS), D15.3 (VSS), D16.3 (VSS), D17.3 (VSS), D18.3 (VSS), D19.3 (VSS), D20.3 (VSS), J1.3, J2.3, J3.1, J4.A12 (GND), J4.B12 (GND), J4.S1 (SHIELD), R2.2, R3.2, R4.1, R5.1, U1.4 (GND)
unnamed: C1.1, J3.2
unnamed: D1.2 (DOUT), D2.4 (DIN)
unnamed: D2.2 (DOUT), D3.4 (DIN)
unnamed: D3.2 (DOUT), D4.4 (DIN)
unnamed: D4.2 (DOUT), D5.4 (DIN)
unnamed: D5.2 (DOUT), D6.4 (DIN)
unnamed: D6.2 (DOUT), D7.4 (DIN)
unnamed: D7.2 (DOUT), D8.4 (DIN)
unnamed: D8.2 (DOUT), D9.4 (DIN)
unnamed: D9.2 (DOUT), D10.4 (DIN)
unnamed: D10.2 (DOUT), D11.4 (DIN)
unnamed: D11.2 (DOUT), D12.4 (DIN)
unnamed: D12.2 (DOUT), D13.4 (DIN)
unnamed: D13.2 (DOUT), D14.4 (DIN)
unnamed: D14.2 (DOUT), D15.4 (DIN)
unnamed: D15.2 (DOUT), D16.4 (DIN)
unnamed: D16.2 (DOUT), D17.4 (DIN)
unnamed: D17.2 (DOUT), D18.4 (DIN)
unnamed: D18.2 (DOUT), D19.4 (DIN)
unnamed: D19.2 (DOUT), D20.4 (DIN)
unnamed: D20.2 (DOUT), J2.2
unnamed: D21.2 (A), U1.6 (PB1)
unnamed: D21.1 (K), R3.1
unnamed: J4.A5 (CC1), R4.2
unnamed: J4.B5 (CC2), R5.2
unnamed: C1.2, R1.2, R2.1, U1.2 (XTAL1/PB3)
VCC: C2.2, D1.1 (VDD), D2.1 (VDD), D3.1 (VDD), D4.1 (VDD), D5.1 (VDD), D6.1 (VDD), D7.1 (VDD), D8.1 (VDD), D9.1 (VDD), D10.1 (VDD), D11.1 (VDD), D12.1 (VDD), D13.1 (VDD), D14.1 (VDD), D15.1 (VDD), D16.1 (VDD), D17.1 (VDD), D18.1 (VDD), D19.1 (VDD), D20.1 (VDD), J1.1, J2.1, J4.A9 (VBUS), J4.B9 (VBUS), R1.1, U1.8 (VCC)

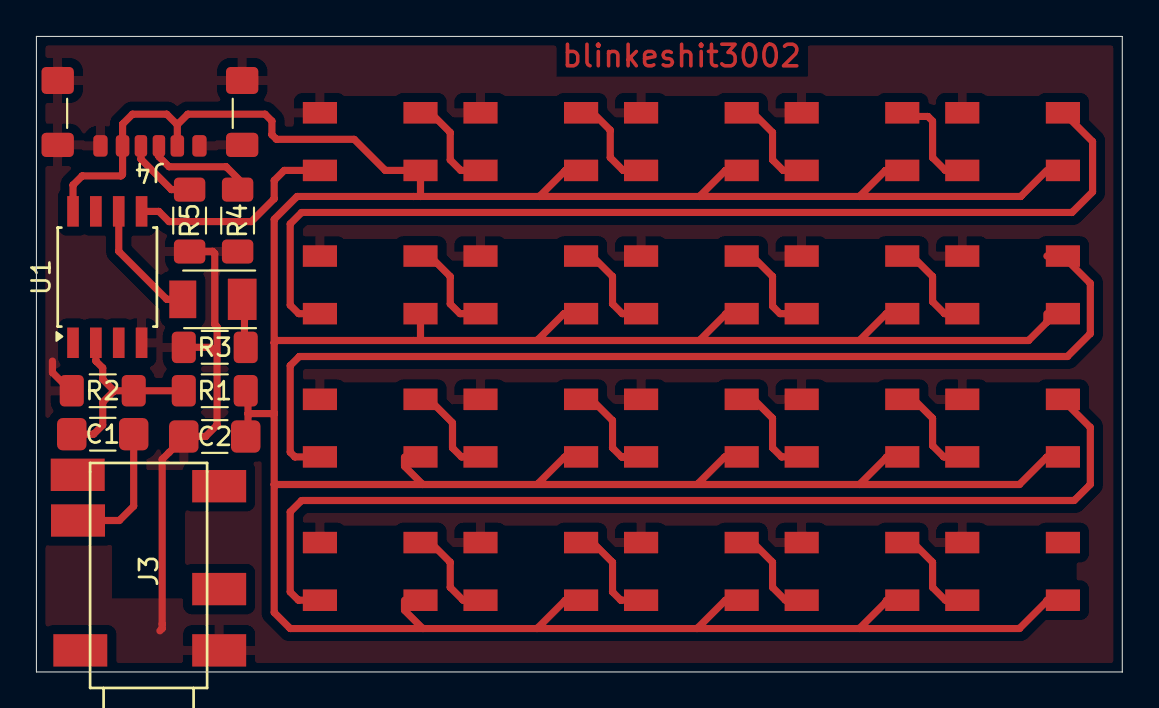
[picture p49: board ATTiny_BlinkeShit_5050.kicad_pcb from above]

Board: 2 copper layers, 60.3 x 35.3 mm, 31 parts (0 on the bottom side), 28 nets.

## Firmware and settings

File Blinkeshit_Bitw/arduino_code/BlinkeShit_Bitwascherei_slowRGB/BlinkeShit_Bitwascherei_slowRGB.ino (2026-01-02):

#include <Adafruit_NeoPixel.h>
#include "pitches.h"

// BlinkeShit for Bitwäscherei
// ***************************
// modified from various code of the 8Bit Mixtape NEO
// http://neo.8bitmixtape.cc/
// using the Audio Upload Bootloader by C.Haberer aka ChrisMikro
// https://github.com/ChrisMicro/TinyAudioBoot
// 

#define NEOPIXELPIN    0
#define NUMPIXELS      8
#define SPEAKERPIN     1

uint8_t showPixel = 0;

byte i;

Adafruit_NeoPixel pixels = Adafruit_NeoPixel(NUMPIXELS, NEOPIXELPIN, NEO_GRB + NEO_KHZ800);

////////////////////////////////////////////////////////////////////////////////////////////////////////////////////////
/* Specific functions of the NEO-Pixel Library
 _____ _____ _____        _         _ 
|   | |   __|     |   ___|_|_ _ ___| |
| | | |   __|  |  |  | . | |_'_| -_| |
|_|___|_____|_____|  |  _|_|_,_|___|_|
                     |_|              
========================================================================================================================
   _________    
  | NEO(x)  |   void setWhiteAllPixel(uint32_t color)                   -> Sets all the pixels to the white level
  |  o___o  |   void displayBinrayValue(uint16_t value, uint32_t color) -> displays binary number
  |__/___\__|   uint32_t Wheel(byte WheelPos)                           -> Input a value 0 to 255 to get a color value.   
                                                                        The colours are a transition r - g - b - back to r. 
                                
//////////////////////////////////////////////////////////////////////////////////////////////////////////////////////*/

void setWhiteAllPixel(uint32_t color)
{
  uint8_t n;
  for (n = 0; n < NUMPIXELS; n++)
  {
    pixels.setPixelColor(n, color, color, color);
  }
}

void setColorAllPixel(uint32_t color)
{
  uint8_t n;
  for (n = 0; n < NUMPIXELS; n++)
  {
    pixels.setPixelColor(n, color);
  }
}

void displayBinrayValue(uint16_t value, uint32_t color)
{
  uint8_t n;
  for (n = 0; n < NUMPIXELS; n++)
  {
    if (value & (1 << n)) pixels.setPixelColor(n, color);
    //else pixels.setPixelColor(n,0); // off
  }
}

void rainbowCycle(uint8_t wait, uint8_t rounds, uint8_t rainbowPixels) {
  uint16_t i, j;

  for (j = 0; j < 256 * rounds; j++) { 
    for (i = 0; i < rainbowPixels; i++) {
      pixels.setPixelColor(i, Wheel(((i * 256 / rainbowPixels) + j) & 255));
    }
    pixels.show();
    delay(wait);
  }
}

uint32_t Wheel(byte WheelPos) {
  WheelPos = 255 - WheelPos;
  if (WheelPos < 85) {
    return pixels.Color(255 - WheelPos * 3, 0, WheelPos * 3);
  }
  if (WheelPos < 170) {
    WheelPos -= 85;
    return pixels.Color(0, WheelPos * 3, 255 - WheelPos * 3);
  }
  WheelPos -= 170;
  return pixels.Color(WheelPos * 3, 255 - WheelPos * 3, 0);
}

// fast pin access
#define AUDIOPIN (1<<SPEAKERPIN)
#define PINLOW (PORTB&=~AUDIOPIN)
#define PINHIGH (PORTB|=AUDIOPIN)

void playSound(long freq_Hz, long duration_ms)
{
  uint16_t n;
  uint32_t delayTime_us;
  uint32_t counts;

  delayTime_us = 1000000UL / freq_Hz / 2;
  counts = duration_ms * 1000 / delayTime_us;

  for (n = 0; n < counts; n++)
  {
    PINHIGH;
    delayMicroseconds(delayTime_us);
    PINLOW;
    delayMicroseconds(delayTime_us);
  }
}


int c[] = {
  NOTE_B4, NOTE_G4, NOTE_D4, NOTE_G4, NOTE_A4, NOTE_D5, PAUSE, NOTE_A4, NOTE_B4, NOTE_A4, NOTE_D4, NOTE_G4 
};

int pauseBetweenNotes = 80;
int noteDuration_ms = 150;

void playMart(int notes[])
{
  // iterate over the notes of the melody:
  for (int thisNote = 0; thisNote <= 11; thisNote++) {

    displayBinrayValue(notes[thisNote],pixels.Color(50,0,50));
    pixels.show(); // This sends the updated pixel color to the hardware.
    playSound( notes[thisNote], noteDuration_ms);
    setColorAllPixel(0); // pixels off
    // to distinguish the notes, set a minimum time between them.
    // the note's duration + 30% seems to work well:
    delay(pauseBetweenNotes);
        
  }
}

////////////////////////////////////////////////////////////////////////////////////////////////////////////////////////
/* the setup routine runs once when you start the tape or press reset
========================================================================================================================
   _________            _                   
  | setup() |   ___ ___| |_ _ _ _ _ 
  |  o___o  |  |_ -| -_|  _| | | . |
  |__/___\__|  |___|___|_| |___|  _|
                               |_|    
//////////////////////////////////////////////////////////////////////////////////////////////////////////////////////*/


void setup(void) {

  pinMode(SPEAKERPIN, OUTPUT);
  uint8_t brightness = 255;
  pixels.begin();
  pixels.setBrightness(brightness);
  
  //rainbowCycle(30,50,32);
  
  setColorAllPixel(0);
  pixels.setBrightness(brightness);
  pixels.show(); // Initialize all pixels to 'off'
    
  playMart(c);
  
}

////////////////////////////////////////////////////////////////////////////////////////////////////////////////////////
/* The main loop to put all your code
========================================================================================================================
   _________    _    
  | loop()  |  | |___ ___ ___ 
  |  o___o  |  | | . | . | . | 
  |__/___\__|  |_|___|___|  _| 
                         |_| 
//////////////////////////////////////////////////////////////////////////////////////////////////////////////////////*/

void loop(void) {

  rainbowCycle(30,50,32);

}

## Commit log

2019-11-26 adding Kicad files
    [BlinkeShit_Example.kicad_pcb, BlinkeShit_Example.sch]
2020-01-20 maybe new bitbadge
    [BlinkeShit_Example.kicad_pcb]
2020-03-04 adding LUMA-box
    [BlinkeShitLUMO_RGB.kicad_pcb, LUMO_hackCase.scad, LUMO_hackCase_main4.stl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]
2020-03-09 new parametric design
    [LUMO_4x4_Top_hackCase.stl, LUMO_4x4_hackCase.stl, LUMO_hackCase_main4.stl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]
2020-06-15 adding the Bitw Blinkeshit
    [2d_cover.dxf, 2d_randli.dxf, 2d_top.dxf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]
2026-01-02 added new blinkeshit
    [ATTiny_BlinkeShit_5050.kicad_pcb, ATTiny_BlinkeShit_5050.kicad_sch, case-Lid.stl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]
2026-01-02 updating all
    [BlinkeShit_Case.scad, CE3_PO-Button.3mf]
2026-01-05 modified openscad to customize thickness of cover
    [case-Lid.stl, case.scad, case.stl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]
2026-01-05 small edits on openscad file
    [case.scad]
